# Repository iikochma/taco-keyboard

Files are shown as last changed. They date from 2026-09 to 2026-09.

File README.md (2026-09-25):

# Taco Keyboard

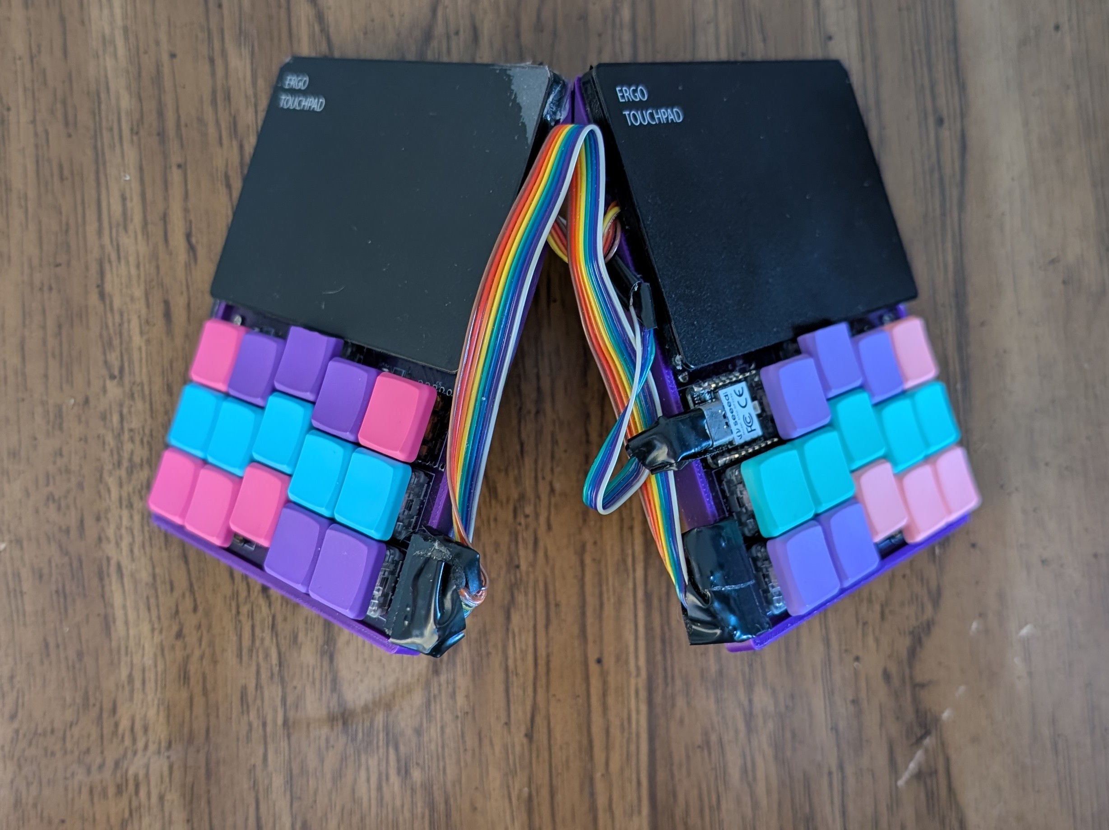
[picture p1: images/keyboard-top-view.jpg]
keyboard overview


A highly ergonomic custom mechanical keyboard designed using KiCad, QMK, and Shapr3D.

The keyboard uses a single-piece design with approximately 60° tenting, integrated pointing devices for both hands, and a highly optimized keymap inspired by the Hands Down layout and Ben Vallack's 18-key keyboard concepts.

## Key Features

- 29-key custom layout ("30% keyboard")

- Approximately 60° tenting and aggressive inward rotation

- Dual integrated trackpads

- Custom reversible PCB designed in KiCad

- Custom QMK firmware

- Custom 3D-printed enclosure designed in Shapr3D

## Design Goals

The project was created to explore extreme ergonomic keyboard design while maintaining high typing efficiency.

The keymap is heavily inspired by the Hands Down layout and Ben Vallack's 18-key workflow. While the keyboard contains 29 keys, the majority of daily typing is performed using approximately 20 keys combined with layers and modifiers.

The layout was further optimized for LaTeX-heavy workflows, reducing hand movement for frequently used symbols and commands.

## Hardware

A single reversible PCB design is used for both sides of the keyboard, reducing manufacturing complexity and cost.

## Repository Structure

- `cad/` - Shapr3D, STEP, and STL files

- `firmware/` - QMK firmware

- `images/` - Photos and renders

- `pcb/` - KiCad project files

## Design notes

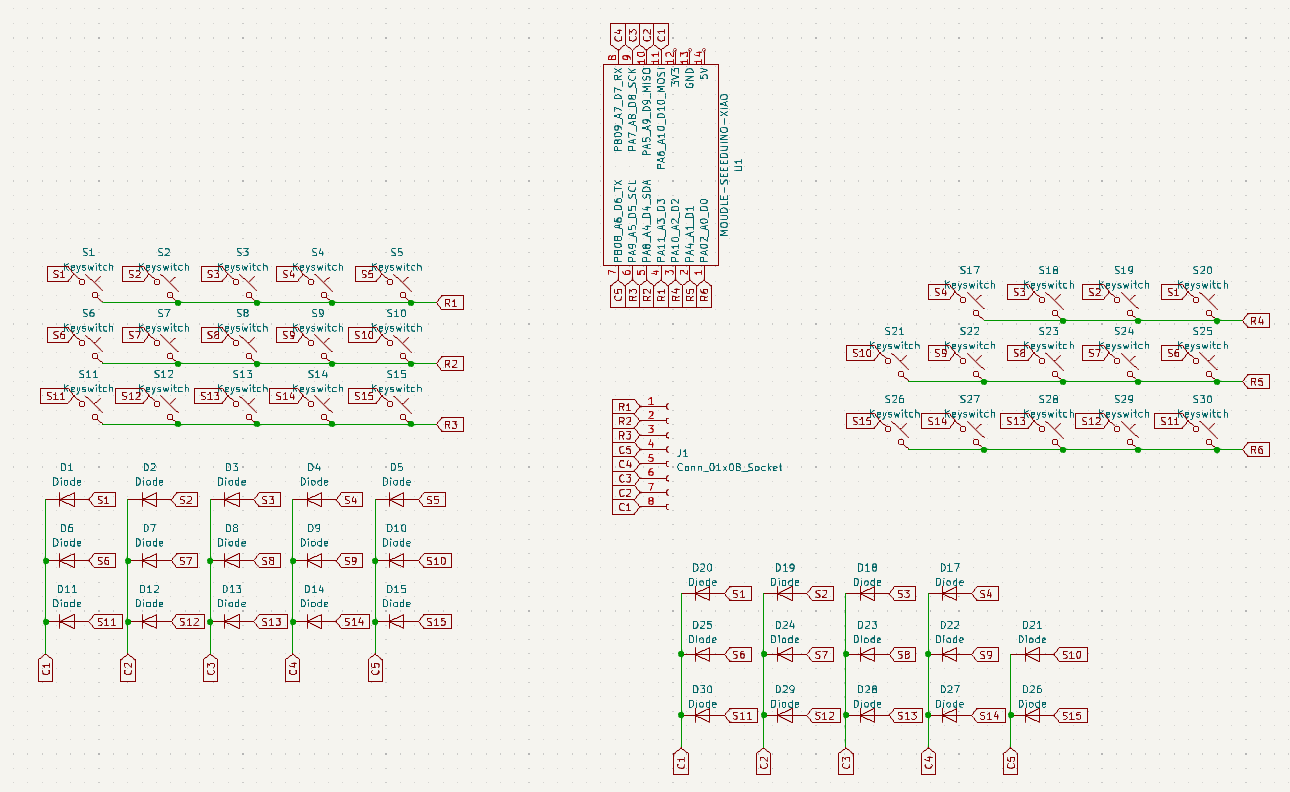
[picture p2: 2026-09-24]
images/pcb-schematic.png

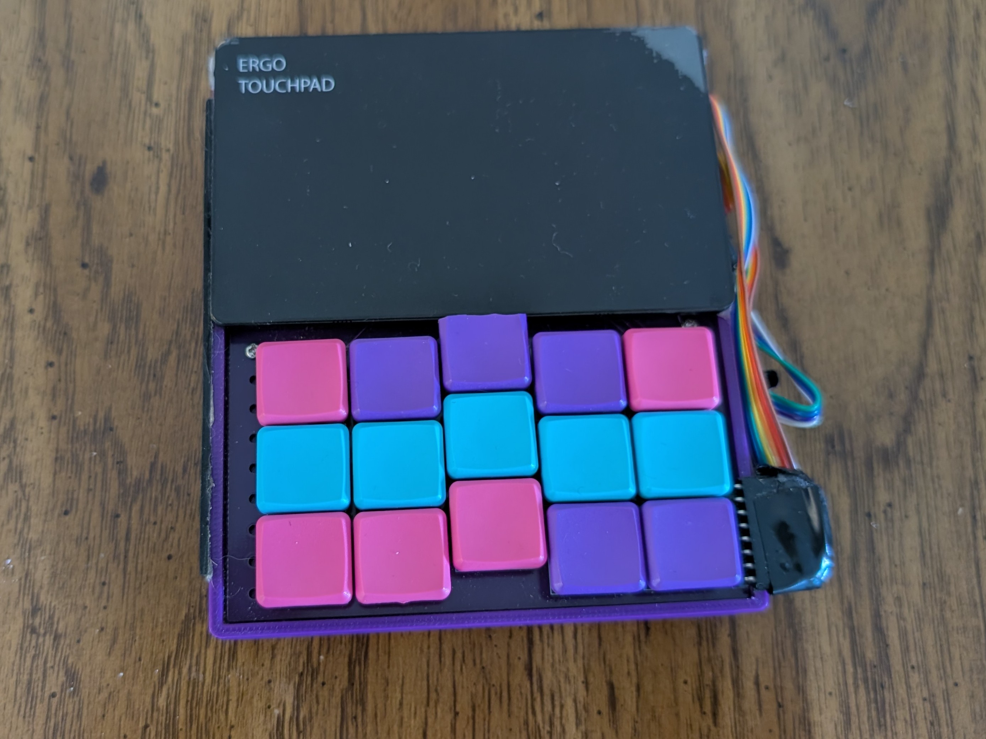
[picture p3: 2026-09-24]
images/keyboard-left-hand.jpg

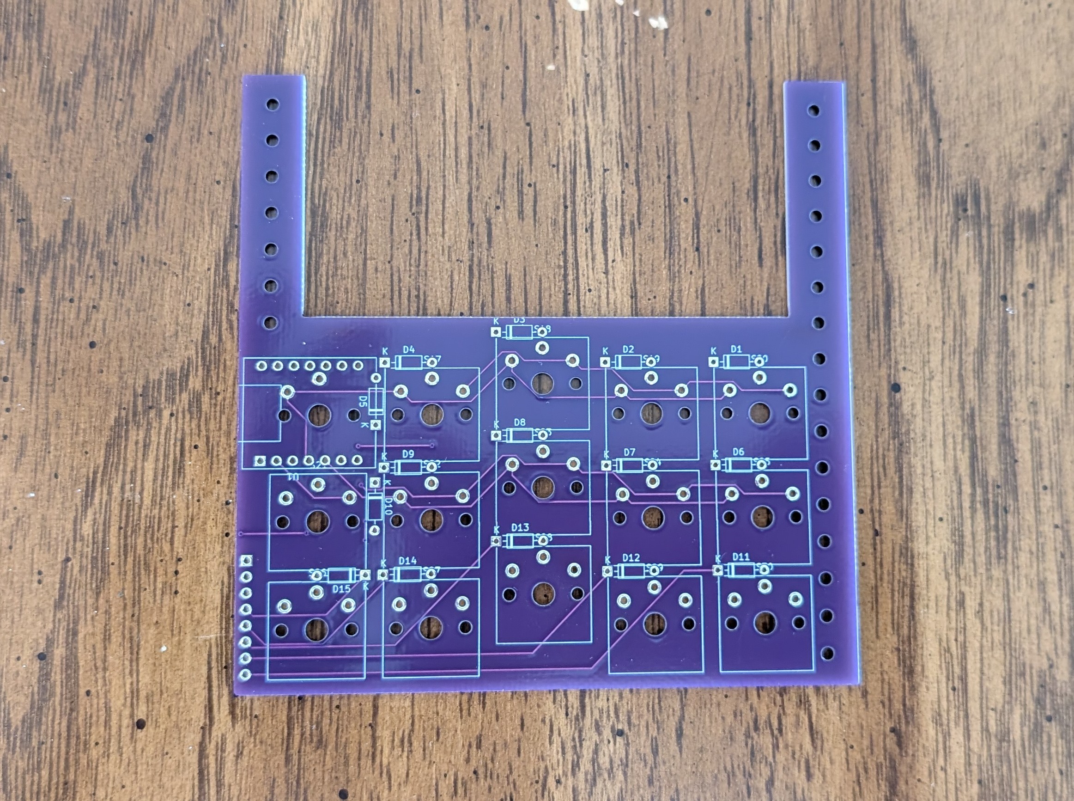
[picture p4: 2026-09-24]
images/pcb-right-side.jpg

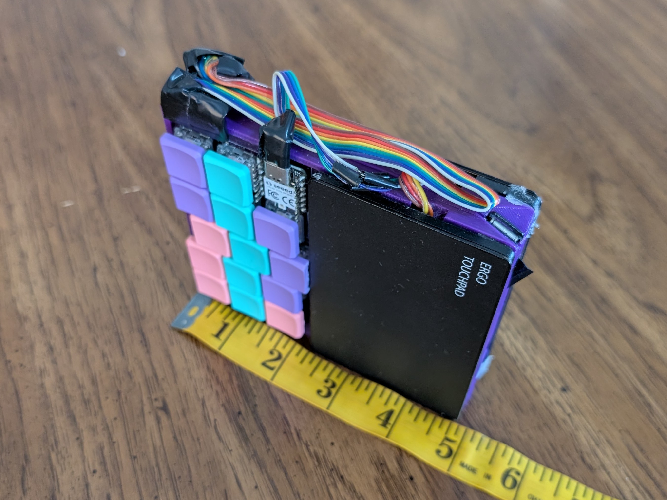
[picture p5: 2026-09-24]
images/keyboard-folded-with-scale.jpg

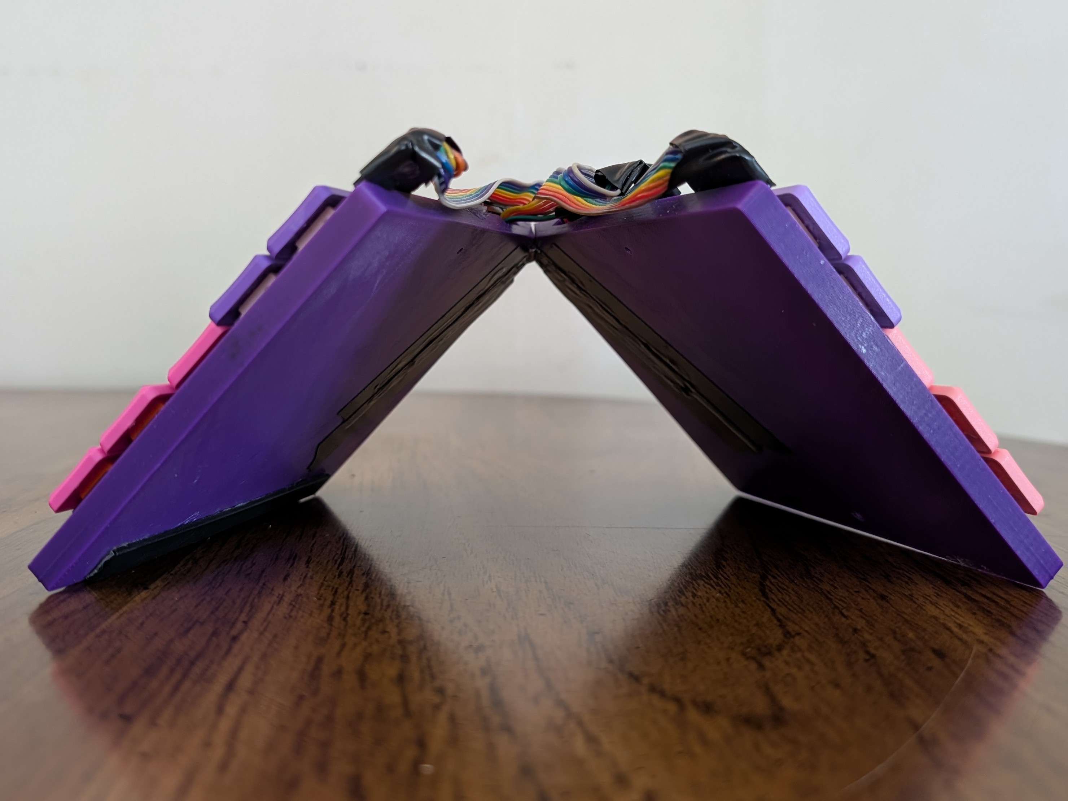
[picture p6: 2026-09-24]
images/keyboard-tenting.jpg

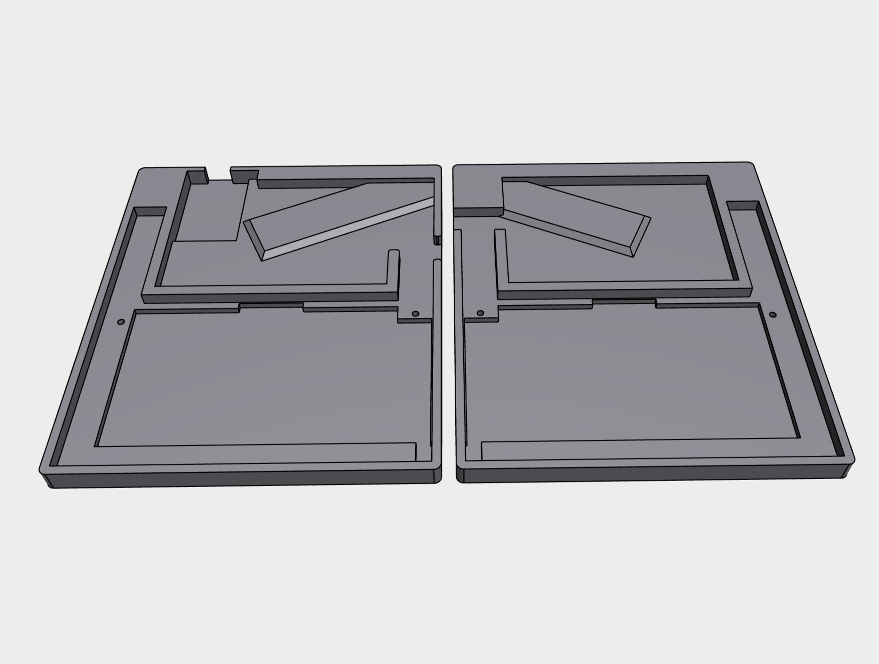
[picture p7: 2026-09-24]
images/case-render-top.PNG

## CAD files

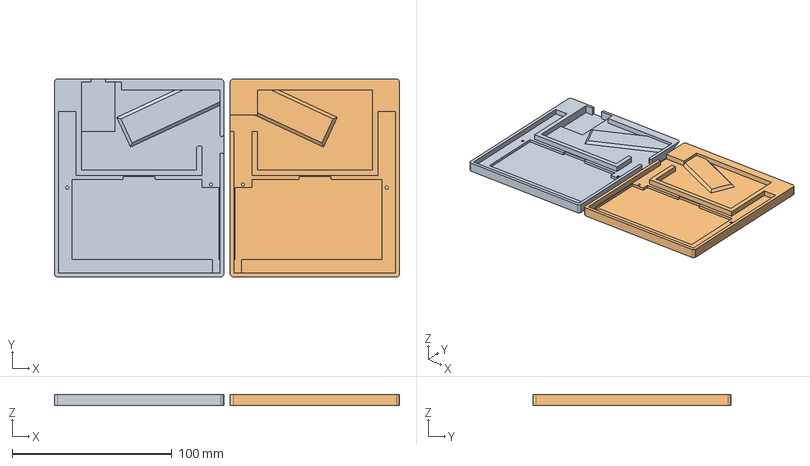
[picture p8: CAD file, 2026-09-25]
cad/taco-case.step
216.0 x 124.0 x 7.00 mm

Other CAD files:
cad/taco-case.stl

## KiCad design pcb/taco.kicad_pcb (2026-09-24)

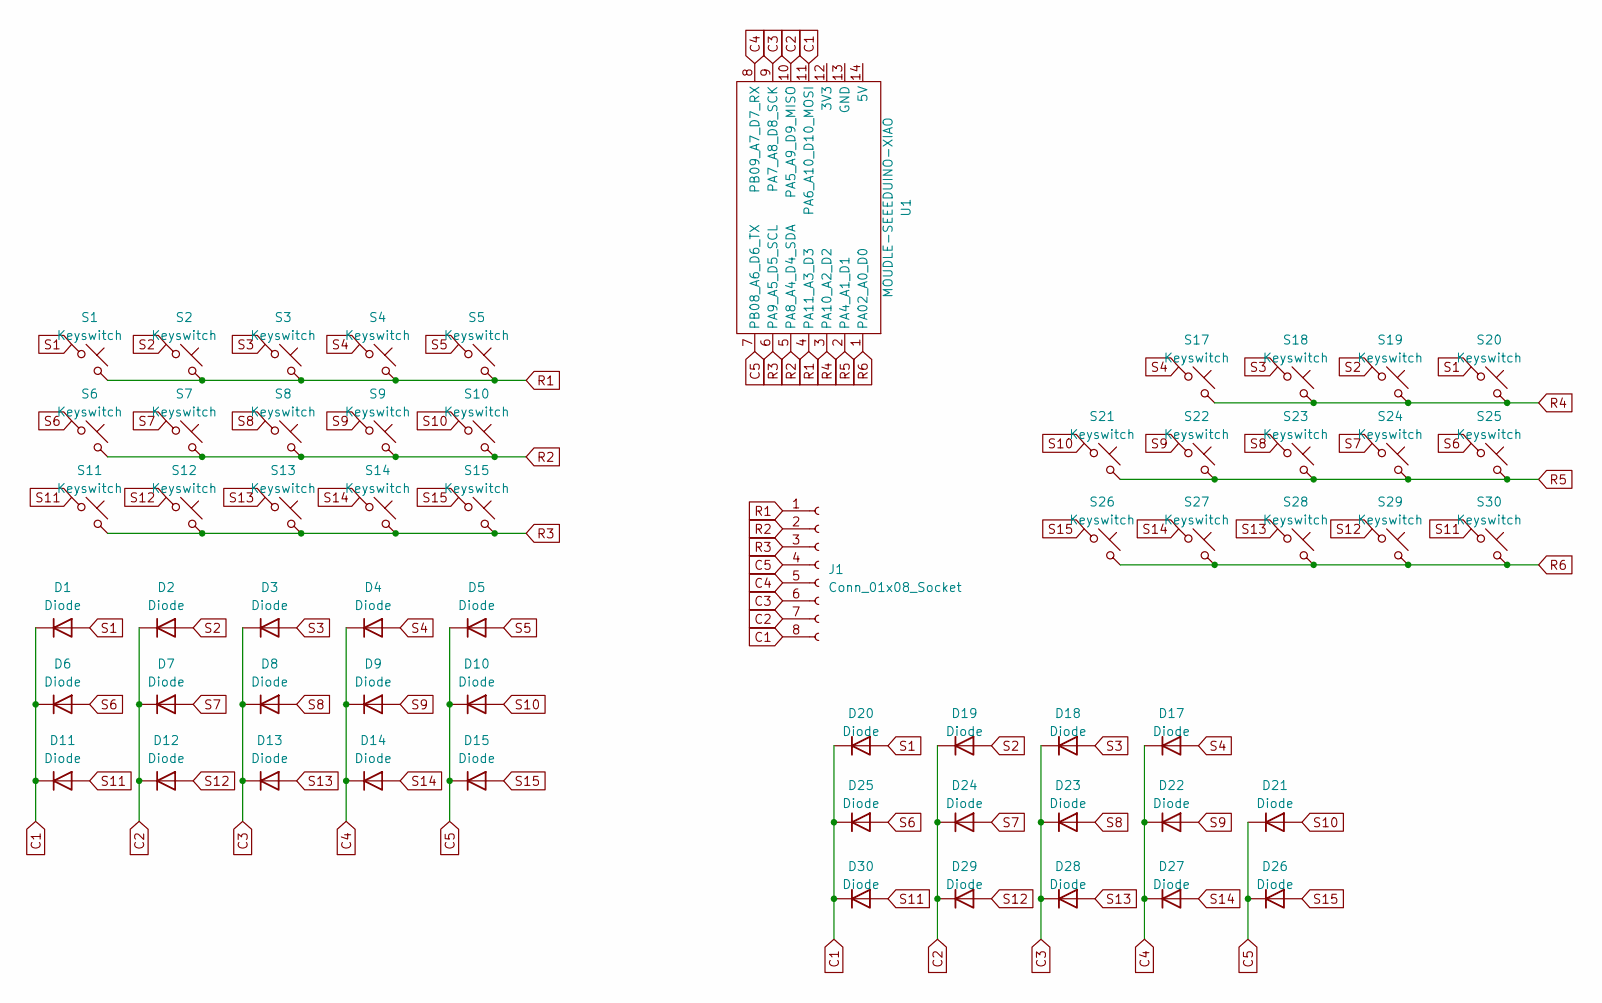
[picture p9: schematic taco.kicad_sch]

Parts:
D1, D2, D3, D4, D5, D6, D7, D8, D9, D10, D11, D12, D13, D14, D15, D17, D18, D19, D20, D21, D22, D23, D24, D25, D26, D27, D28, D29, D30: Diode; Diode_DO-35
J1: Conn_01x08_Socket; PinSocket_1x08_P2.54mm_Vertical
S1, S2, S3, S4, S5, S6, S7, S8, S9, S10, S11, S12, S13, S14, S15, S17, S18, S19, S20, S21, S22, S23, S24, S25, S26, S27, S28, S29, S30: Keyswitch; Choc_V1_1.00u
U1: MOUDLE-SEEEDUINO-XIAO; MOUDLE14P-2.54-21X17.8MM

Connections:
C1: D1.1 (K), D6.1 (K), D11.1 (K), D20.1 (K), D25.1 (K), D30.1 (K), J1.8, U1.11 (PA6_A10_D10_MOSI)
C2: D2.1 (K), D7.1 (K), D12.1 (K), D19.1 (K), D24.1 (K), D29.1 (K), J1.7, U1.10 (PA5_A9_D9_MISO)
C3: D3.1 (K), D8.1 (K), D13.1 (K), D18.1 (K), D23.1 (K), D28.1 (K), J1.6, U1.9 (PA7_A8_D8_SCK)
C4: D4.1 (K), D9.1 (K), D14.1 (K), D17.1 (K), D22.1 (K), D27.1 (K), J1.5, U1.8 (PB09_A7_D7_RX)
C5: D5.1 (K), D10.1 (K), D15.1 (K), D21.1 (K), D26.1 (K), J1.4, U1.7 (PB08_A6_D6_TX)
R1: J1.1, S1.2, S2.2, S3.2, S4.2, S5.2, U1.4 (PA11_A3_D3)
R2: J1.2, S6.2, S7.2, S8.2, S9.2, S10.2, U1.5 (PA8_A4_D4_SDA)
R3: J1.3, S11.2, S12.2, S13.2, S14.2, S15.2, U1.6 (PA9_A5_D5_SCL)
R4: S17.2, S18.2, S19.2, S20.2, U1.3 (PA10_A2_D2)
R5: S21.2, S22.2, S23.2, S24.2, S25.2, U1.2 (PA4_A1_D1)
R6: S26.2, S27.2, S28.2, S29.2, S30.2, U1.1 (PA02_A0_D0)
S1: D1.2 (A), D20.2 (A), S1.1, S20.1
S2: D2.2 (A), D19.2 (A), S2.1, S19.1
S3: D3.2 (A), D18.2 (A), S3.1, S18.1
S4: D4.2 (A), D17.2 (A), S4.1, S17.1
S5: D5.2 (A), S5.1
S6: D6.2 (A), D25.2 (A), S6.1, S25.1
S7: D7.2 (A), D24.2 (A), S7.1, S24.1
S8: D8.2 (A), D23.2 (A), S8.1, S23.1
S9: D9.2 (A), D22.2 (A), S9.1, S22.1
S10: D10.2 (A), D21.2 (A), S10.1, S21.1
S11: D11.2 (A), D30.2 (A), S11.1, S30.1
S12: D12.2 (A), D29.2 (A), S12.1, S29.1
S13: D13.2 (A), D28.2 (A), S13.1, S28.1
S14: D14.2 (A), D27.2 (A), S14.1, S27.1
S15: D15.2 (A), D26.2 (A), S15.1, S26.1

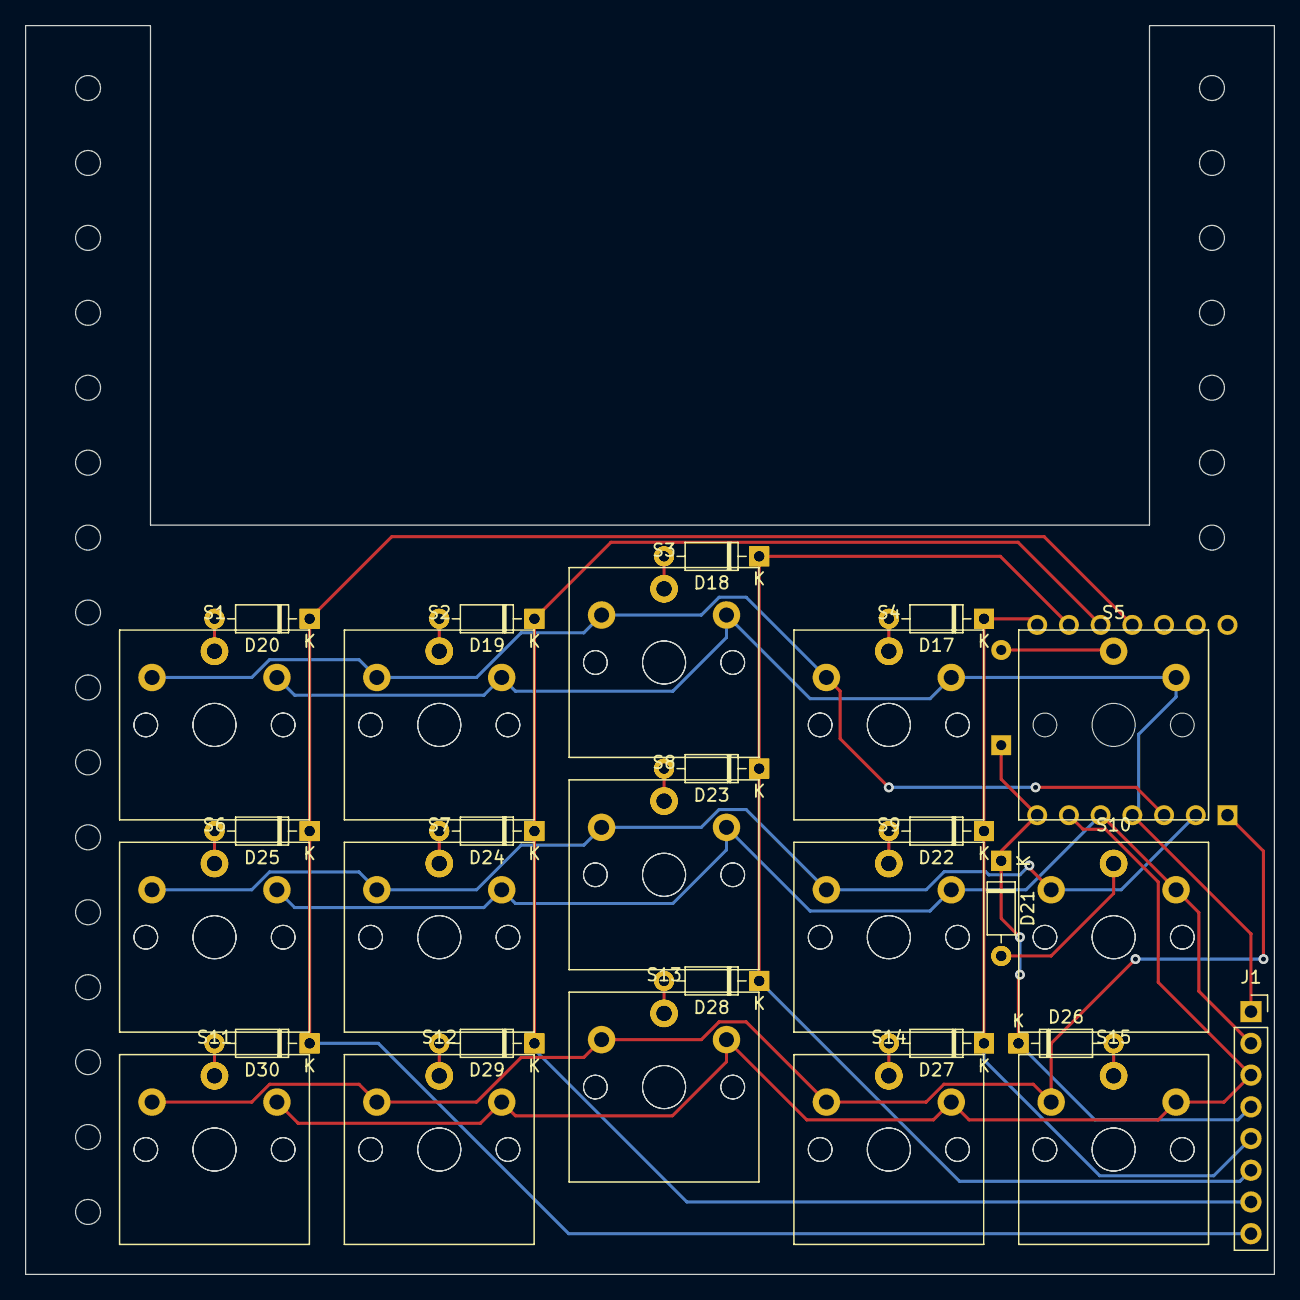
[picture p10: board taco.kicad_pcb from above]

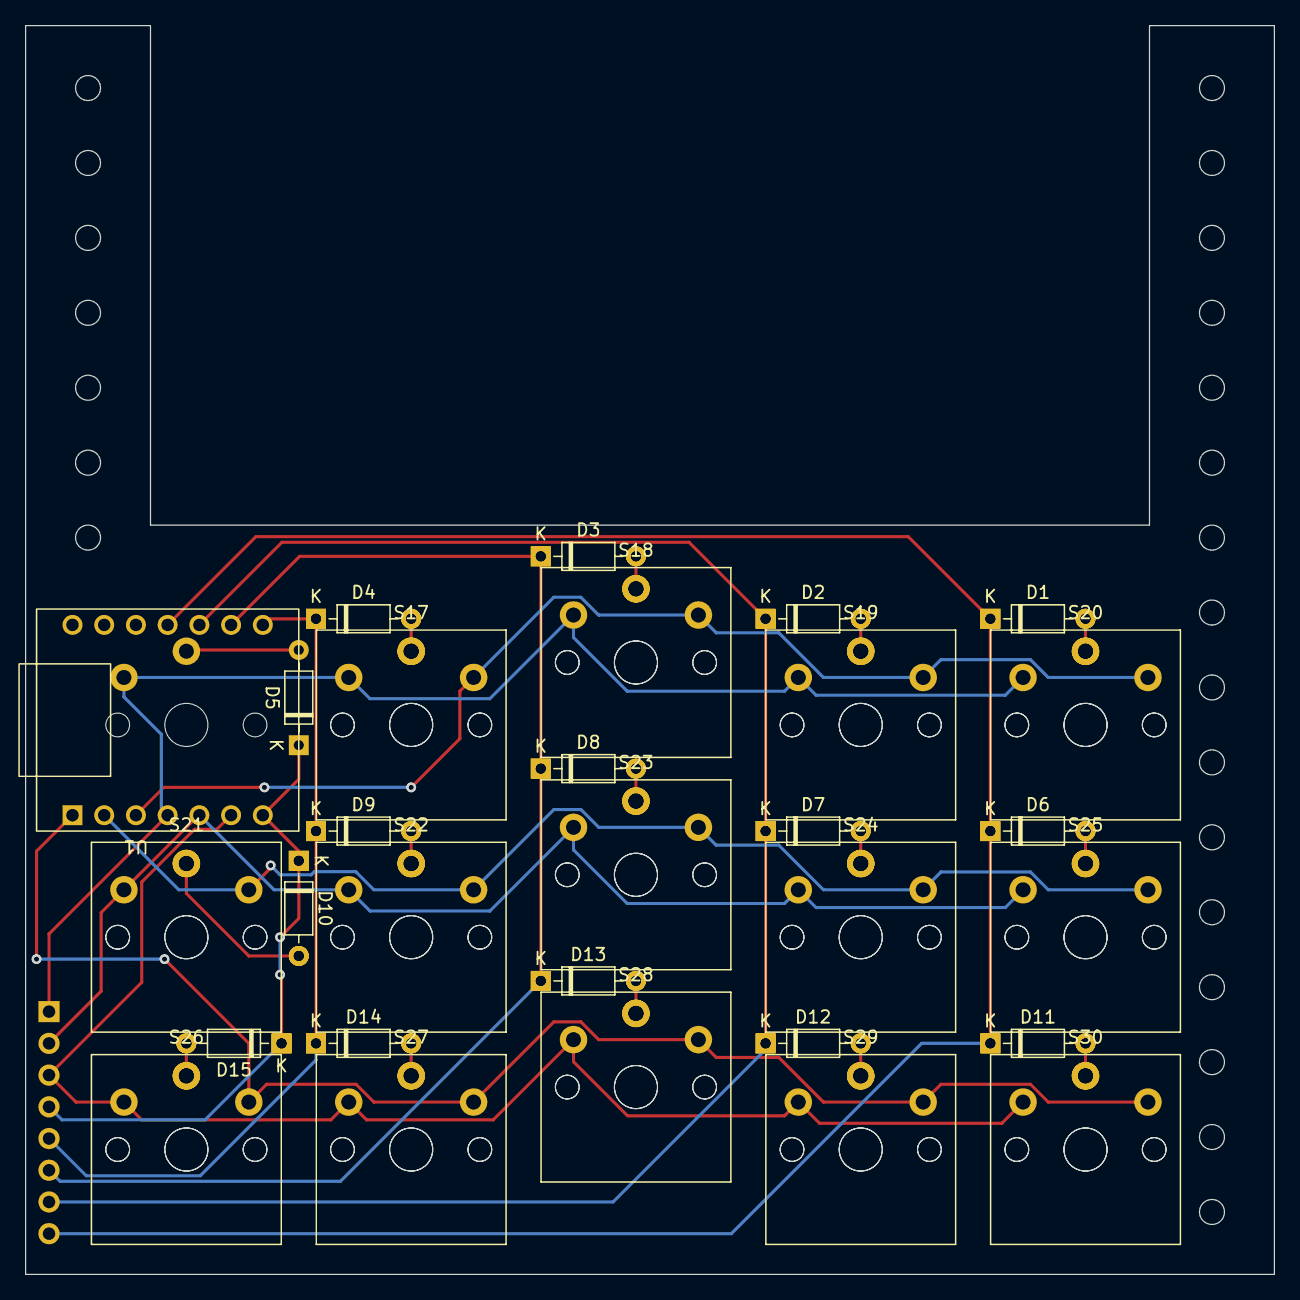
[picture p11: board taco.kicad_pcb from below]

Board: 2 copper layers, 100.0 x 100.0 mm, 60 parts (30 on the bottom side), 26 nets.

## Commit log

2026-09-24 Add KiCad design files
    [taco.kicad_pcb, taco.kicad_sch]
2026-09-25 Add CAD files
    [taco-case.step, taco-case.stl]
